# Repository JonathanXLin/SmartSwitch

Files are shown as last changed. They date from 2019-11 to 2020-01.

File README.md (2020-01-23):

# SmartSwitch
Easy home IoT. Splice between home wiring (120-240V AC/7-32V DC) to control anything downstream from the web.

<br>
<p align="center"> 
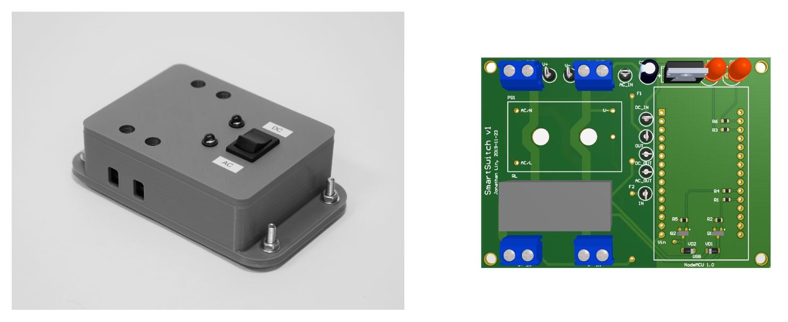
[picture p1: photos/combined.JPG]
  
</p>
<br>

The ESP8266 microcontroller is utilized as a webserver. When an HTTP request is received, the relay state is set accordingly and an HTML form is sent to the user's browser. HTML forms are stored on the ESP8266's SPI flash.

<br>
<p align="center"> 
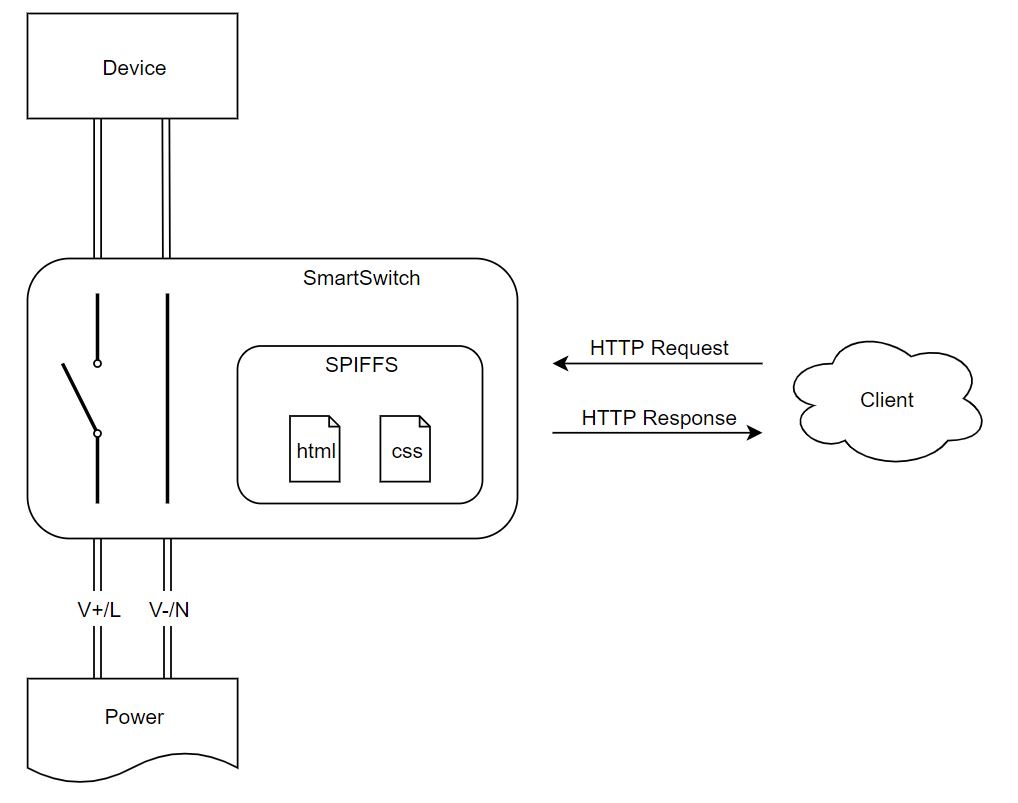
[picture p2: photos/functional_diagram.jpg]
  
</p>
<br>

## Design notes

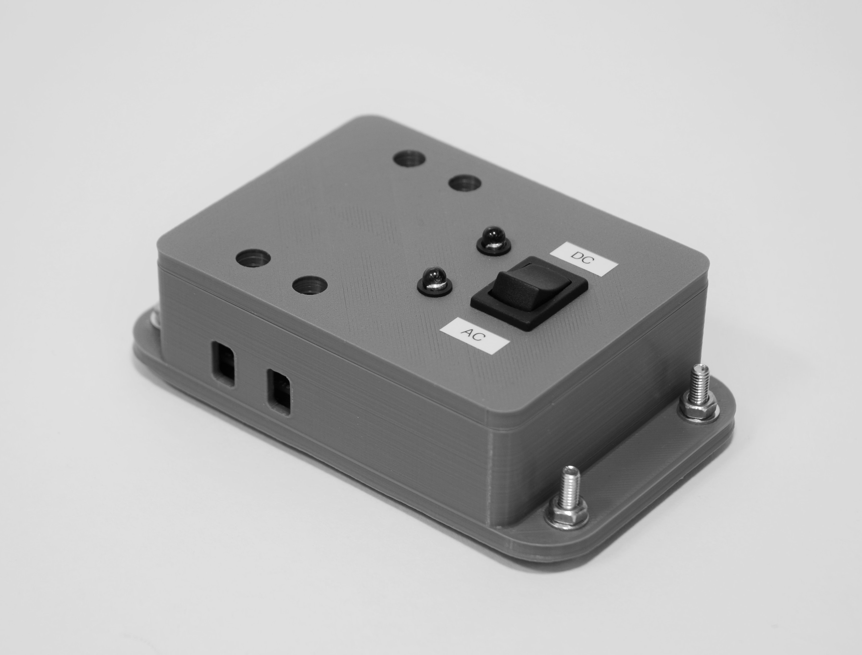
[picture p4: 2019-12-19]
photos/complete.jpg

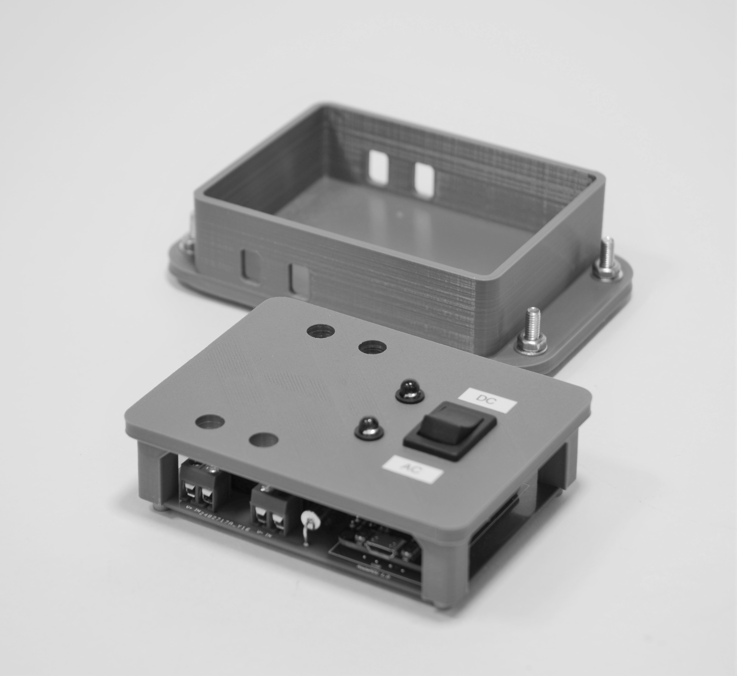
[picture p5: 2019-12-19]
photos/dissected.jpg

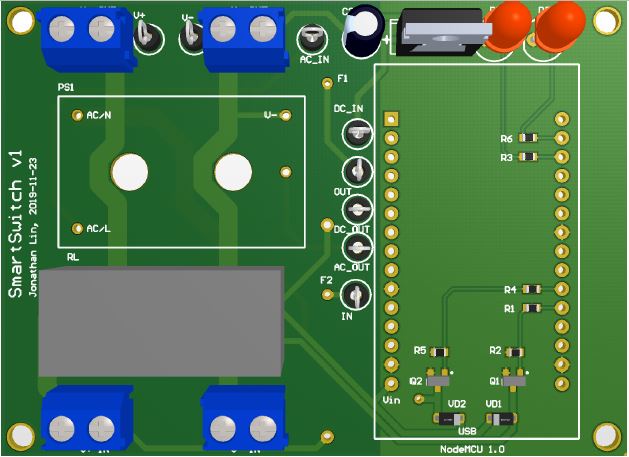
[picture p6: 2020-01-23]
photos/board.jpg

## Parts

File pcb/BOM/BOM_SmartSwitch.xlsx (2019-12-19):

Comment | Description | Designator | Manufacturer Part Number | Quantity | Price | Extended Price
TE Connectivity 796949-2 | Connector Terminal Blocks 2 Position 5.08mm Solder Straight Thru-Hole 17.5A/Contact | V+ IN, V+ OUT, V- IN, V- OUT | 796949-2 | 4 | $1.05 | $4.20
10uF | Cap, Alu Elec, 1uf, 50v, Rad | C2 | ESK105M050AC3AA | 1 | $0.16 | $0.16
3JQ 500-R | Fuse Subminiature Fast Acting 0.5A 350V Axial 5 X 15mm Glass CE/CSA/UL/cULus | F1 | 3JQ 500-R | 1 | $0.32 | $0.32
3JQ 1-R | Fuse Subminiature Fast Acting 1A 350V Axial 5 X 15mm Glass CE/CSA/PSE/UL/cULus | F2 | 3JQ 1-R | 1 | $0.32 | $0.32
NodeMCU 1.0 | Nodemcu V2 Lua Based ESP8266 Dev | NodeMCU 1.0 | 113990105 | 1
IRM-01-5 | AC/DC CONVERTER 5V 1W | PS1 | IRM-01-5 | 1 | $6.03 | $6.03
DMN65D8L-7 | Trans MOSFET N-CH 60V 0.31A Automotive 3-Pin SOT-23 T/R | Q1, Q2 | DMN65D8L-7 | 2 | $0.17 | $0.34
330 | Precision resistor, SMD [Panasonic Automotive & Industrial Systems] ERJ3EKF3300V Precision resistor, SMD | R1, R3, R4, R6 | ERJ-3EKF3300V | 4 | $0.10 | $0.40
10k | Resistor Thick Film 0603 10k Ohm 1% 1/10 Watt ±100ppm °C Surface Mount Punched Carrier Tape and Reel | R2, R5 | ERJ-3EKF1002V | 2 | $0.10 | $0.20
G5RL-K1A-E-DC5 | General Purpose Relay SPST-NO (1 Form A) 5VDC Coil Through Hole | RL | G5RL-K1A-E-DC5 | 1 | $4.34 | $4.34
LM7805CT/NOPB | Linear voltage regulator [ST micro] LM7805CV Linear voltage regulator 2A THT | U1 | LM7805CT/NOPB | 1 | $1.54 | $1.54
1N4148W-TP | Diode: switching; SMD; 100V; 0.15A; 4ns; 400mW; Package: reel, tape | VD1, VD2 | 1N4148W-TP | 2 | $0.10 | $0.20
PM5GT | LED 2.3X7MM GREEN PANEL MOUNT | PANEL MOUNT | SSI-LXH072GD‎ | 1 | $1.20 | $1.20
PM5YT | LED 2.3X7MM RED PANEL MOUNT | PANEL MOUNT | ‎SSI-LXH072ID‎ | 1 | $1.17 | $1.17
GRS-4022-1600 | SWITCH ROCKER DPDT 16A 125V | PANEL MOUNT | GRS-4022-1600 | 1 | $1.38 | $1.38
 |  |  |  |  | Total | $21.80

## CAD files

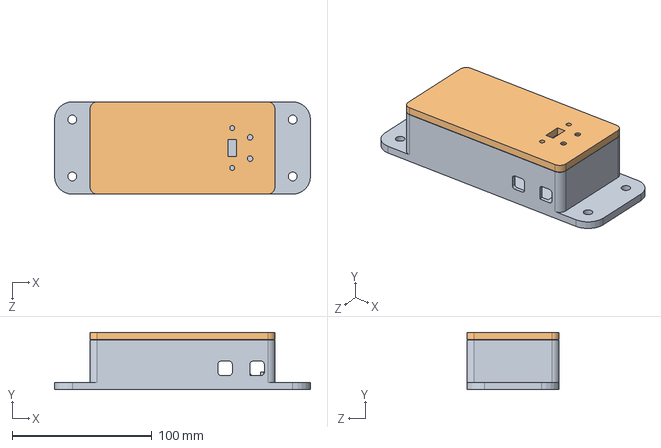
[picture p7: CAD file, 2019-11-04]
stl/p1.0/SmartSwitch_Assembly.SLDASM
182.9 x 40.9 x 66.0 mm
SmartSwitch_Case
SmartSwitch_Lid

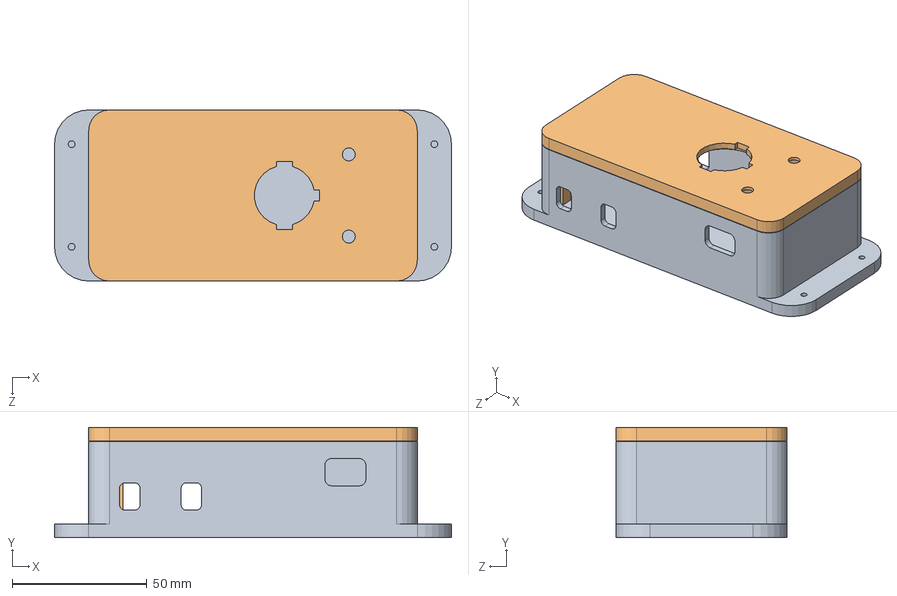
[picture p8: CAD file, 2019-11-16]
stl/p1.1/SmartSwitch_Assembly.SLDASM
147.3 x 40.8 x 63.5 mm
SmartSwitch_Case
SmartSwitch_Lid

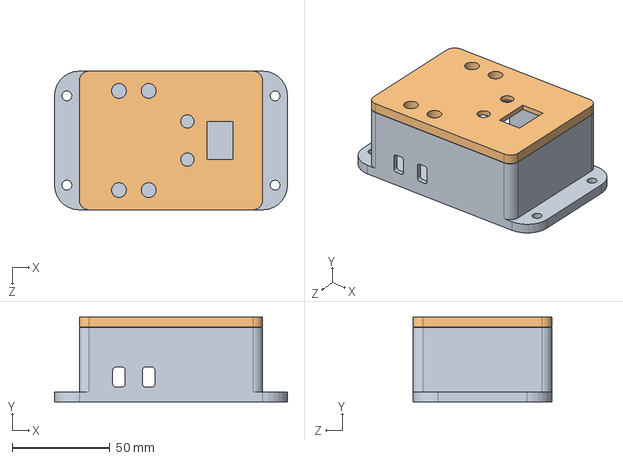
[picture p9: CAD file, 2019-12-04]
stl/v1.0/SmartSwitch_Assembly.SLDASM
119.4 x 43.4 x 71.1 mm
SmartSwitch_Enclosure
SmartSwitch_Lid

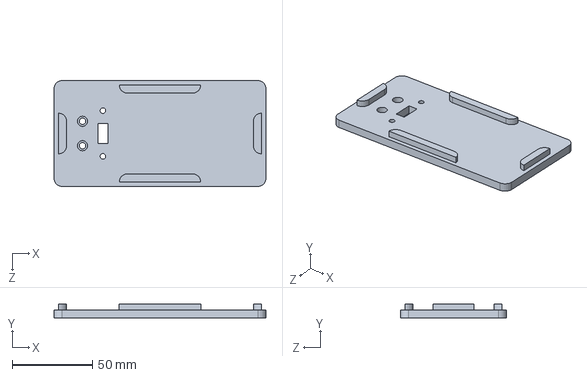
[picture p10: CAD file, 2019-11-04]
stl/p1.0/SmartSwitch_Lid.SLDPRT
132.1 x 8.89 x 66.0 mm

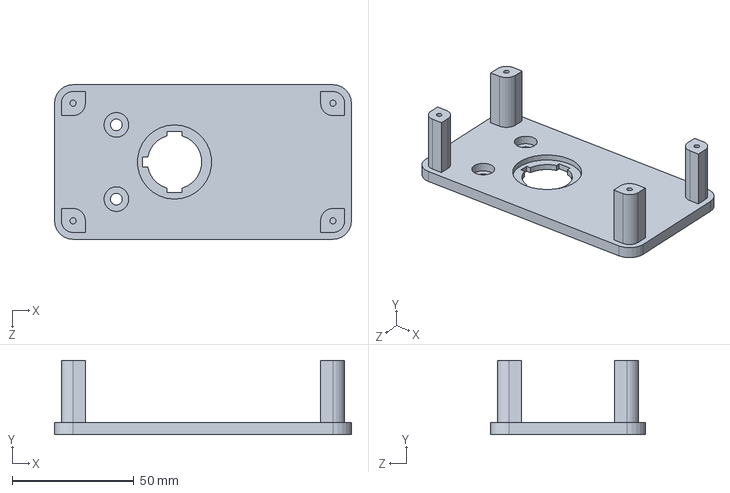
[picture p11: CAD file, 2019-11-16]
stl/p1.1/SmartSwitch_Lid.SLDPRT
121.9 x 30.5 x 63.5 mm

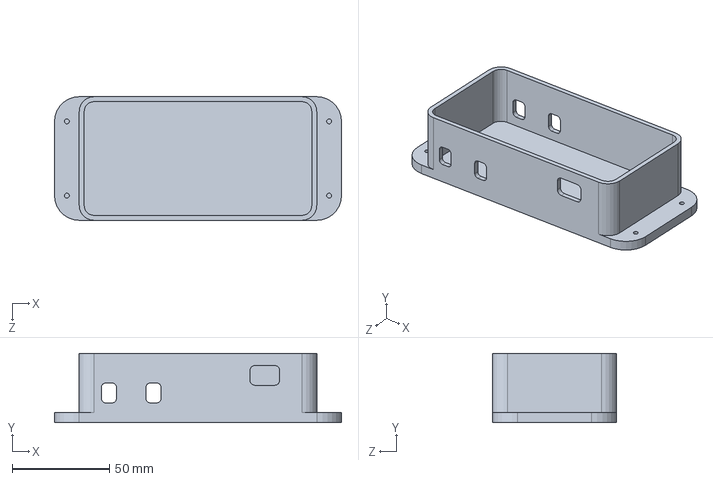
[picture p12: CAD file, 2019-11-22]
stl/p1.2/SmartSwitch_Case.SLDPRT
147.3 x 35.6 x 63.5 mm

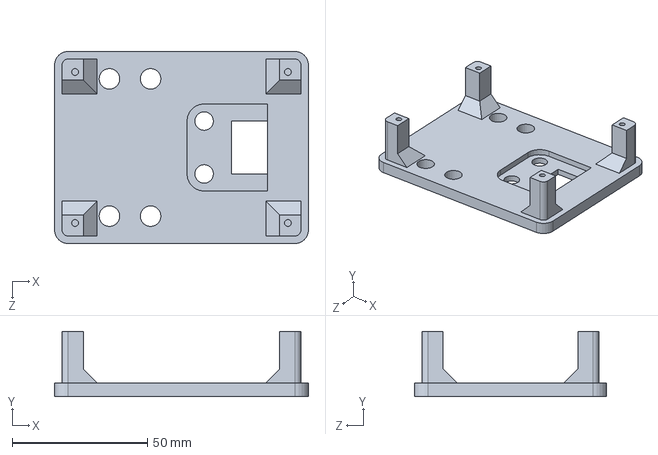
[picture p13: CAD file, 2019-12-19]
stl/v1.0/SmartSwitch_Lid.SLDPRT
94.0 x 24.1 x 71.1 mm

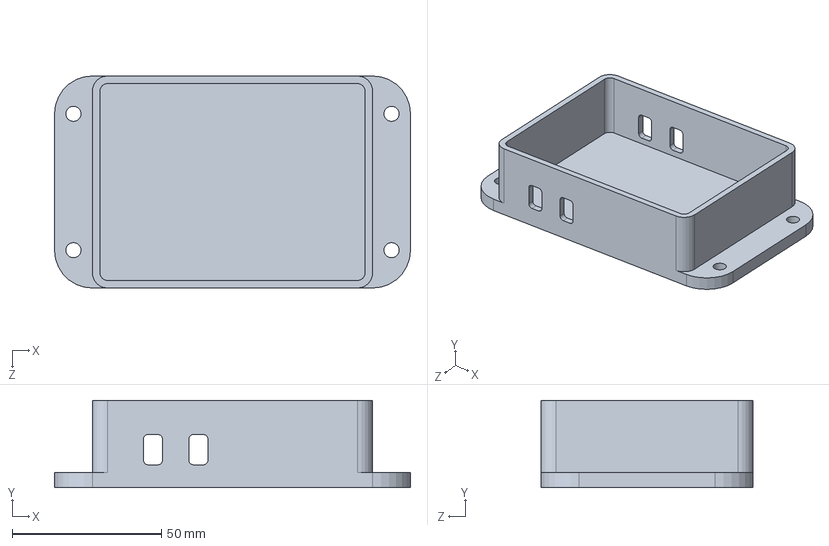
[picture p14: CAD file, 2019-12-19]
stl/v1.0/SmartSwitch_Enclosure.SLDPRT
119.4 x 29.2 x 71.1 mm

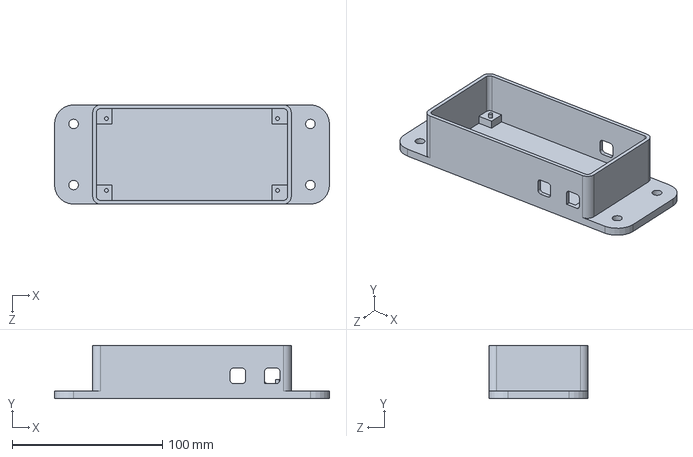
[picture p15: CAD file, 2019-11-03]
stl/p1.0/SmartSwitch_Case.SLDPRT
182.9 x 35.6 x 66.0 mm

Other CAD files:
stl/p1.2/SmartSwitch_Lid.SLDPRT
stl/p1.1/SmartSwitch_Case.SLDPRT
stl/p1.0/SmartSwitch_Case.STL
stl/p1.0/SmartSwitch_Lid.STL
stl/p1.1/SmartSwitch_Case.STL
stl/p1.1/SmartSwitch_Lid.STL
stl/p1.2/SmartSwitch_Case.STL
stl/p1.2/SmartSwitch_Lid.STL
stl/v1.0/SmartSwitch_Enclosure.STL
stl/v1.0/SmartSwitch_Lid.STL

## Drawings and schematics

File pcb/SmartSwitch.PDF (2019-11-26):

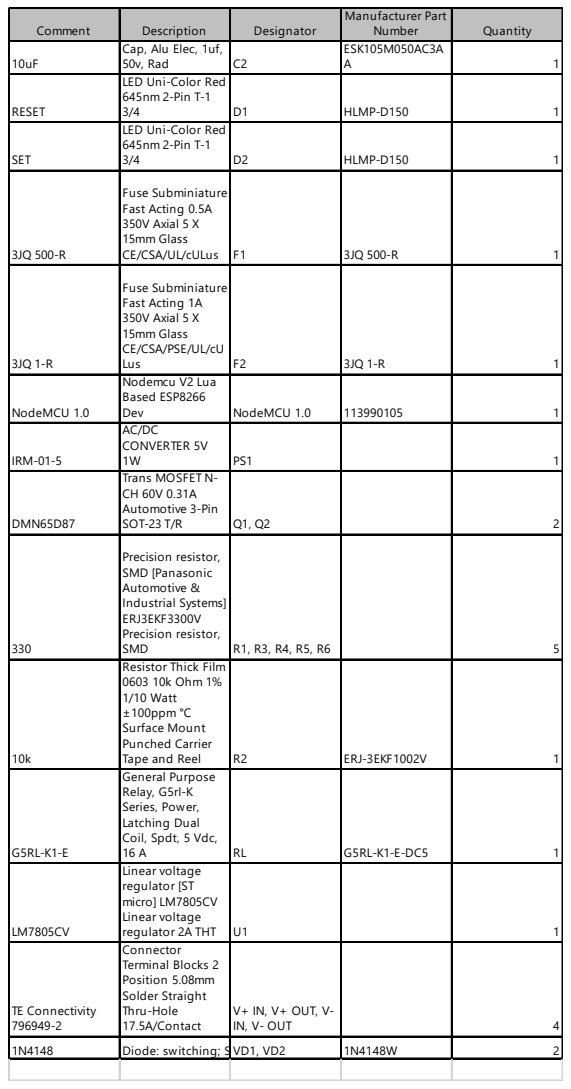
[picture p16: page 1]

Comment | Description | Designator | Manufacturer Part Number | Quantity

10uF | Cap, Alu Elec, 1uf, 50v, Rad | C2 | ESK105M050AC3A A | 1

RESET | LED Uni-Color Red 645nm 2-Pin T-1 3/4 | D1 | HLMP-D150 | 1

SET | LED Uni-Color Red 645nm 2-Pin T-1 3/4 | D2 | HLMP-D150 | 1

3JQ 500-R | Fuse Subminiature Fast Acting 0.5A 350V Axial 5 X 15mm Glass CE/CSA/UL/cULus | F1 | 3JQ 500-R | 1

3JQ 1-R | Fuse Subminiature Fast Acting 1A 350V Axial 5 X 15mm Glass CE/CSA/PSE/UL/cU Lus | F2 | 3JQ 1-R | 1

NodeMCU 1.0 | Nodemcu V2 Lua Based ESP8266 Dev | NodeMCU 1.0 | 113990105 | 1

IRM-01-5 | AC/DC CONVERTER 5V 1W | PS1 | | 1

DMN65D87 | Trans MOSFET N-CH 60V 0.31A Automotive 3-Pin SOT-23 T/R | Q1, Q2 | | 2

330 | Precision resistor, SMD [Panasonic Automotive & Industrial Systems] ERJ3EKF3300V Precision resistor, SMD | R1, R3, R4, R5, R6 | | 5

10k | Resistor Thick Film 0603 10k Ohm 1% 1/10 Watt ±100ppm °C Surface Mount Punched Carrier Tape and Reel | R2 | ERJ-3EKF1002V | 1

G5RL-K1-E | General Purpose Relay, G5rl-K Series, Power, Latching Dual Coil, Spdt, 5 Vdc, 16 A | RL | G5RL-K1-E-DC5 | 1

LM7805CV | Linear voltage regulator [ST micro] LM7805CV Linear voltage regulator 2A THT | U1 | | 1

TE Connectivity 796949-2 | Connector Terminal Blocks 2 Position 5.08mm Solder Straight Thru-Hole 17.5A/Contact | V+ IN, V+ OUT, V-IN, V- OUT | | 4

1N4148 | Diode: switching; SVD1, VD2 | | 1N 4148W | 2

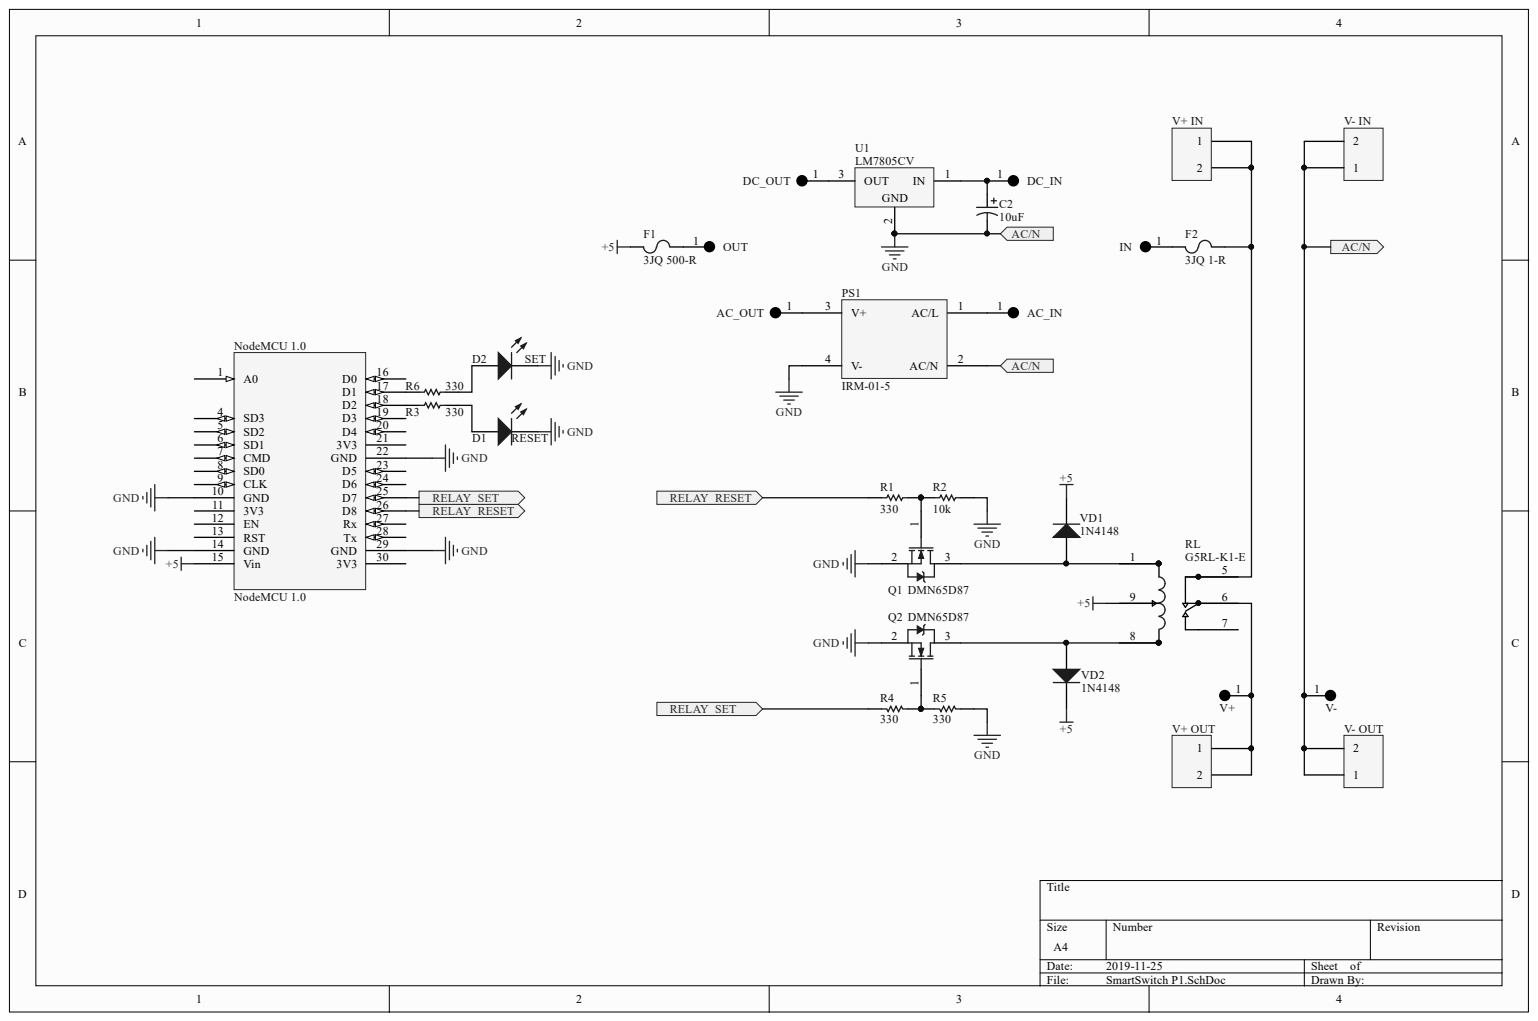
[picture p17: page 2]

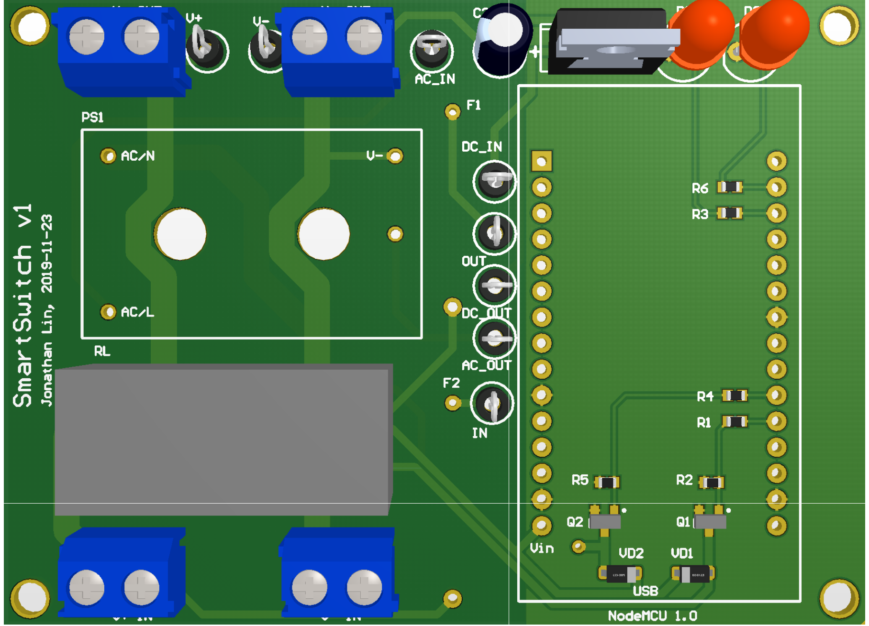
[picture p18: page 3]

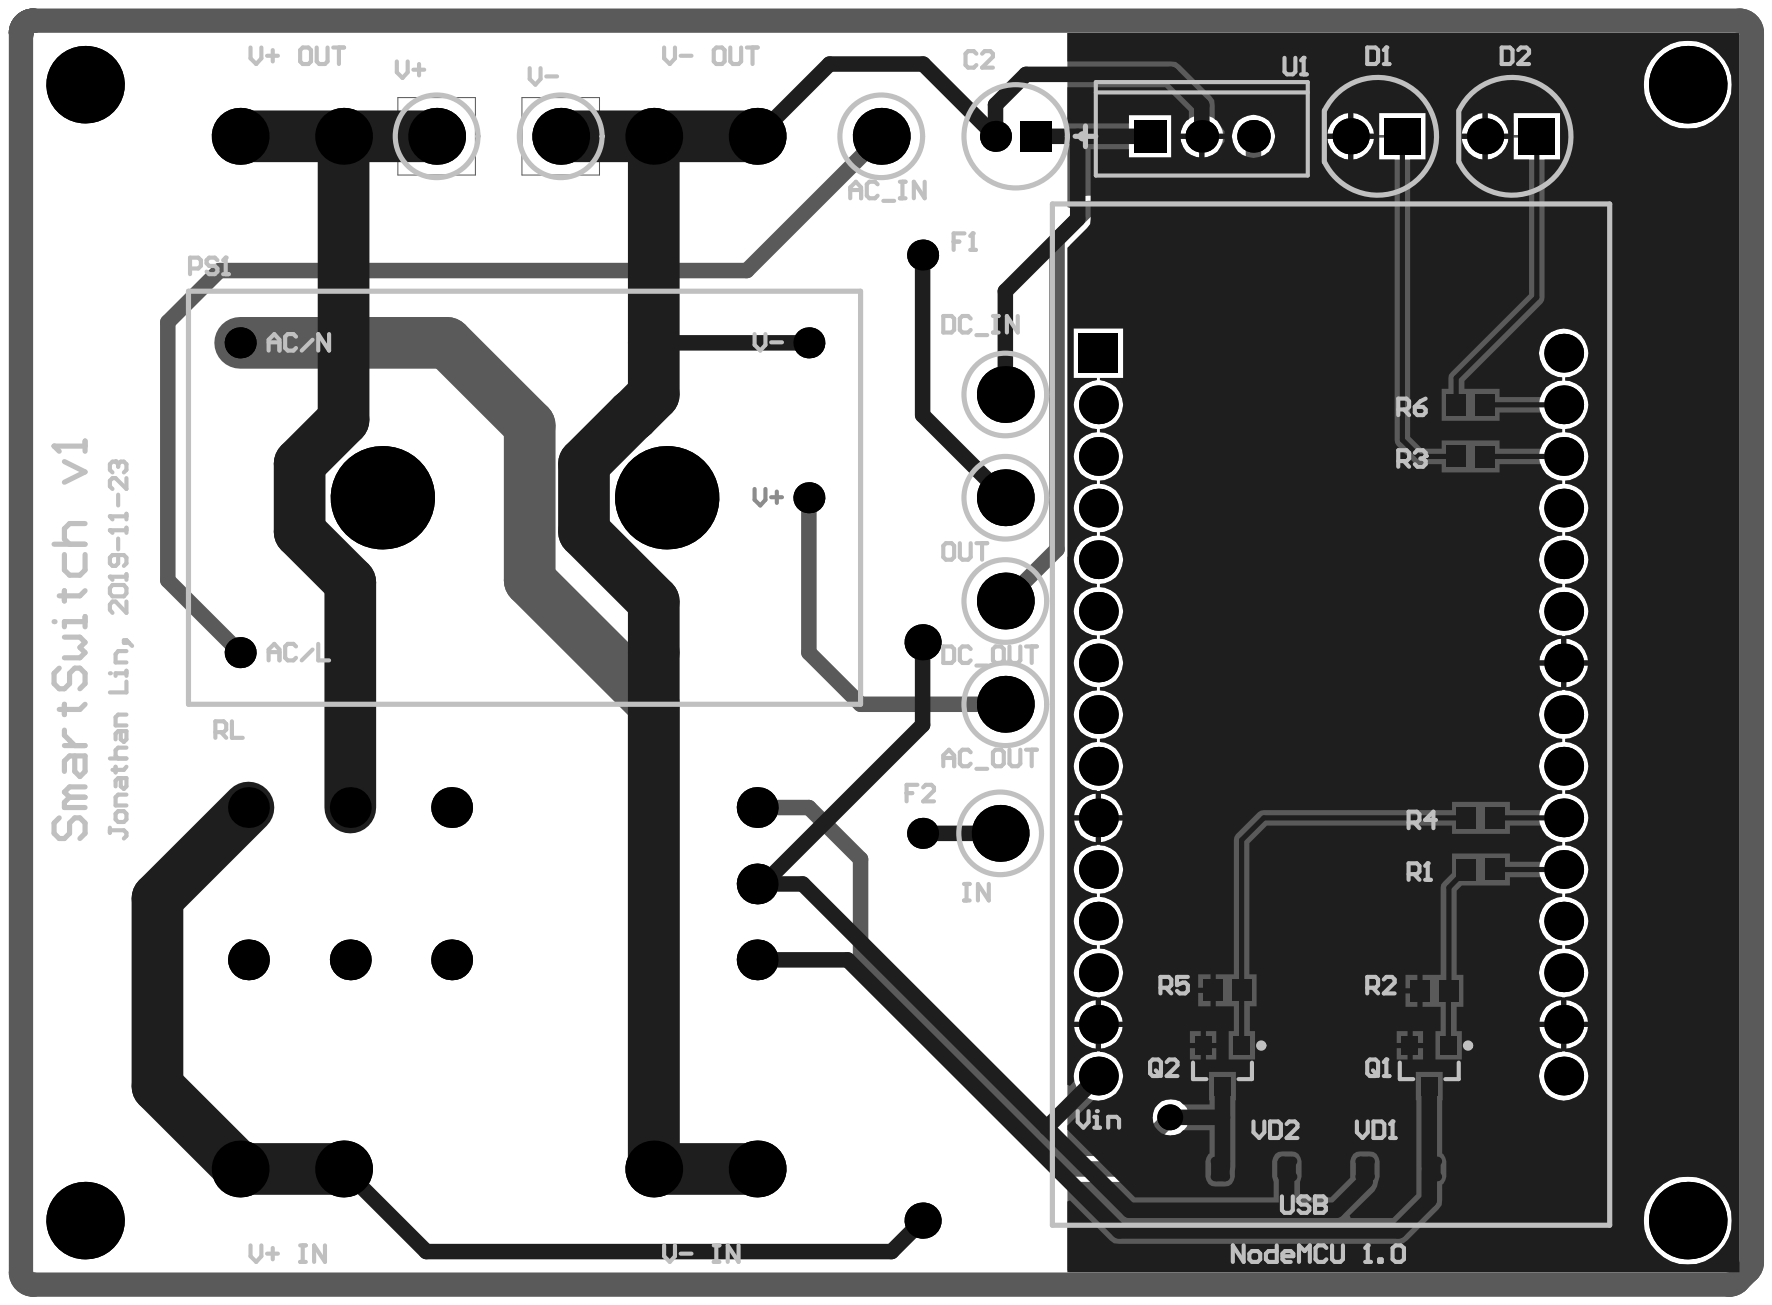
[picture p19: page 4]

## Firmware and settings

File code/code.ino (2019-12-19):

#include <ESP8266WiFi.h>
#include <WiFiClient.h>
#include <ESP8266WiFiMulti.h>
#include <ESP8266mDNS.h>
#include <ESP8266WebServer.h>
#include "FS.h"   // Include the SPIFFS library

#include "wifi_credentials.hpp"

// Assign output variables to GPIO pins
const int pin_set = 13; // D7
const int pin_reset = 15; // D8

const int pin_set_led = 5; // D1
const int pin_reset_led = 4; // D2

bool master_state = false; // State of SmartSwitch

bool set_state = false;
int set_timeout = 99999; // Initialized to not time out initially
bool reset_state = false;
int reset_timeout = 99999; // Initialized to not time out initially

ESP8266WiFiMulti wifiMulti;     // Create an instance of the ESP8266WiFiMulti class, called 'wifiMulti'

ESP8266WebServer server(80);    // Create a webserver object that listens for HTTP request on port 80

String getContentType(String filename); // convert the file extension to the MIME type
bool handleFileRead(String path);       // send the right file to the client (if it exists)

void setup() {

  Serial.begin(115200);
  while(!Serial) { delay(100); }

  // Initialize pin modes
  pinMode(pin_set, OUTPUT);
  pinMode(pin_reset, OUTPUT);
  pinMode(pin_set_led, OUTPUT);
  pinMode(pin_reset_led, OUTPUT);

  // Initialize pin states
  digitalWrite(pin_set, LOW);
  digitalWrite(pin_reset, LOW);
  digitalWrite(pin_set_led, LOW);
  digitalWrite(pin_reset_led, LOW);

  // Flash LEDs
  for (int i=0; i<2; i++)
  {
    digitalWrite(pin_set_led, HIGH);
    digitalWrite(pin_reset_led, HIGH);

    delay(150);

    digitalWrite(pin_set_led, LOW);
    digitalWrite(pin_reset_led, LOW);

    delay(150);
  }

  // Connect to wifi
  wifiMulti.addAP(network_name, network_password); // add Wi-Fi networks you want to connect to

  Serial.println("Connecting ...");
  int i = 0;
  while (wifiMulti.run() != WL_CONNECTED) { // Wait for the Wi-Fi to connect
    delay(250);
    Serial.print('.');
  }
  Serial.println('\n');
  Serial.print("Connected to ");
  Serial.println(WiFi.SSID());
  Serial.print("IP address:\t"); // Print IP address
  Serial.println(WiFi.localIP());

  if (MDNS.begin("SmartSwitch")) // Start the mDNS responder for esp8266.local
    Serial.println("mDNS responder started");
  else 
    Serial.println("Error setting up MDNS responder!");

  SPIFFS.begin(); // Start the SPI Flash Files System
  
  server.onNotFound([]() {                              // If the client requests any URI
    if (!handleFileRead(server.uri()))                  // send it if it exists
      server.send(404, "text/plain", "404: Not Found"); // otherwise, respond with a 404 (Not Found) error
  });

  server.begin(); // Actually start the server
  Serial.println("HTTP server started");
  
  // Initialize to off
  master_state = false; 

  digitalWrite(pin_set, LOW);
  digitalWrite(pin_reset, HIGH);
  digitalWrite(pin_set_led, LOW);
  digitalWrite(pin_reset_led, HIGH);

  reset_state = true;
  reset_timeout = millis() + 500;
  master_state = false;
}

void loop(void) {
  
  ESP.wdtFeed();
  
  server.handleClient();

  // Reset after elapsed time after command
  if (set_state && millis() > set_timeout)
  {
    digitalWrite(pin_set, LOW);
    set_state = false;
  }

  if (reset_state && millis() > reset_timeout)
  {
    digitalWrite(pin_reset, LOW);
    reset_state = false;
  }
}

String getContentType(String filename) { // convert the file extension to the MIME type
  if (filename.endsWith(".html")) return "text/html";
  else if (filename.endsWith(".css")) return "text/css";
  else if (filename.endsWith(".js")) return "application/javascript";
  else if (filename.endsWith(".ico")) return "image/x-icon";
  return "text/plain";
}

bool handleFileRead(String path) { // send the right file to the client (if it exists)

  Serial.println("handleFileRead: " + path);
  
  if (path.endsWith("/"))
  {
    if (master_state)
      path += "button_on.html";
    else
      path += "button_off.html";
  }
  else if (path.endsWith("/button_on.html")) 
  {
    digitalWrite(pin_set, HIGH);
    digitalWrite(pin_reset, LOW);
    digitalWrite(pin_set_led, HIGH);
    digitalWrite(pin_reset_led, LOW);

    set_state = true;
    set_timeout = millis() + 500;
    master_state = true;

    Serial.println(path);
  }
  else if (path.endsWith("/button_off.html"))
  {
    digitalWrite(pin_set, LOW);
    digitalWrite(pin_reset, HIGH);
    digitalWrite(pin_set_led, LOW);
    digitalWrite(pin_reset_led, HIGH);

    reset_state = true;
    reset_timeout = millis() + 500;
    master_state = false;
    
    Serial.println(path);
  }
  
  String contentType = getContentType(path);            // Get the MIME type
  if (SPIFFS.exists(path)) {                            // If the file exists
    File file = SPIFFS.open(path, "r");                 // Open it
    size_t sent = server.streamFile(file, contentType); // And send it to the client
    file.close();                                       // Then close the file again
    return true;
  }
  Serial.println("\tFile Not Found");
  return false;                                         // If the file doesn't exist, return false
}

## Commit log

2019-11-03 stl initial
    [SmartSwitch_Assembly.SLDASM, SmartSwitch_Case.SLDPRT, SmartSwitch_Case.STL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]
2019-11-04 c complete
    [SmartSwitch_Assembly.SLDASM, SmartSwitch_Lid.SLDPRT, SmartSwitch_Lid.STL]
2019-11-06 SPIFFS file system for html, latching relay logic
    [BOM_PartType-SmartSwitch.xlsx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]
2019-11-10 model update
    [SmartSwitch_Assembly.SLDASM, SmartSwitch_Case.SLDPRT, SmartSwitch_Case.STL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]
2019-11-12 watch dog timer reset bug fix
    [SmartSwitch_Lid.SLDPRT, SmartSwitch_Lid.STL]
2019-11-15 Model assembly update
    [SmartSwitch_Case.SLDPRT, SmartSwitch_Case.STL, SmartSwitch_Lid.SLDPRT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]
2019-11-16 Model updates
    [SmartSwitch_Assembly.SLDASM, SmartSwitch_Case.SLDPRT, SmartSwitch_Case.STL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]
2019-11-18 PCB V2
    [BOM_PartType-SmartSwitch.xlsx, BOM_SmartSwitch.xlsx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]
2019-11-22 PCB update
    [BOM_SmartSwitch.xlsx]
2019-11-26 pcb copper trace update
2019-12-04 lid stl update
    [SmartSwitch_Lid.SLDPRT, SmartSwitch_Lid.STL]
2019-12-19 enclosure update
    [SmartSwitch_Enclosure.SLDPRT, SmartSwitch_Enclosure.STL, SmartSwitch_Lid.SLDPRT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]
2019-12-19 bom update
    [BOM_SmartSwitch.xlsx]
